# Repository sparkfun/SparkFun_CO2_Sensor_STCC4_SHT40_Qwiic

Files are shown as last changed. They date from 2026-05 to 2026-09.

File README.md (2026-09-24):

# SparkFun CO2 Sensor - STCC4/SHT41 (Qwiic)

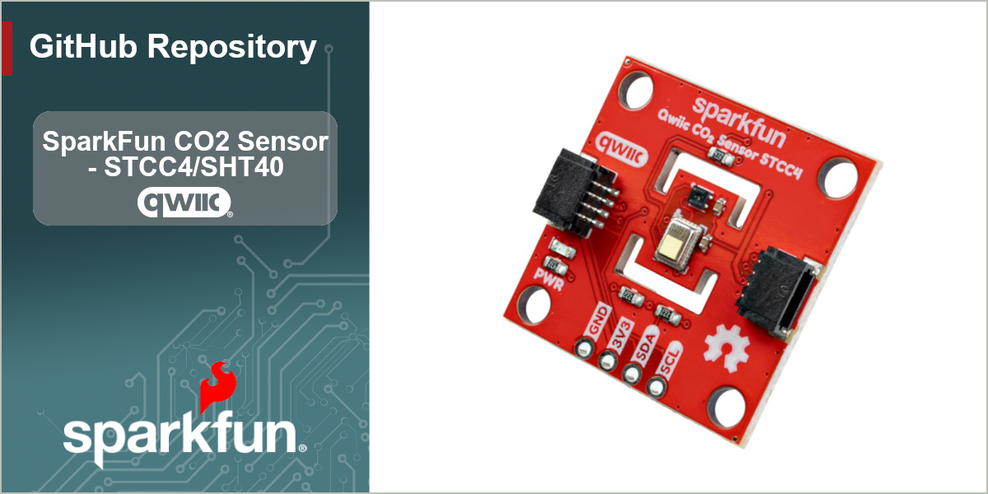
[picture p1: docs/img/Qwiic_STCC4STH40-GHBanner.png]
SparkFun CO2 Sensor - STCC4/SHT40 (Qwiic) (https://www.sparkfun.com/sparkfun-co2-sensor-stcc4-sht40-qwiic.html)


The SparkFun CO2 Sensor - STCC4/SHT40 (Qwiic) is a compact, plug-and-play air quality breakout built around the STCC4 CO₂ sensor paired with a Sensirion SHT41 temperature and humidity sensor for on-board environmental compensation. Connect via the Qwiic connector or the PTH header (GND, 3V3, SDA, SCL) and start reading calibrated CO₂ concentrations, temperature, and relative humidity over I2C in minutes — no external components required.

Designed for our [Qwiic ecosystem](https://www.sparkfun.com/qwiic), this 1" × 1" board plugs straight into any Qwiic-enabled microcontroller. A power LED confirms operation at a glance, and the four mounting holes make permanent installation straightforward. Whether you are monitoring indoor air quality, building a ventilation controller, or logging CO₂ trends in a greenhouse or classroom, the STCC4 delivers accurate, temperature- and humidity-compensated readings in a breadboard-friendly package.

## Repository Contents

* **/docs** - Documentation files for GitHub pages
* **/Documents** - Datasheets, additional product information
* **/Hardware** - KiCad design files (.kicad_sch, .kicad_pcb)
* **/Production** - Production panel files

## Documentation

* **[Library](https://github.com/sparkfun/SparkFun_STCC4_Arduino_Library)** - Arduino library for the SparkFun CO2 Sensor - STCC4/SHT40 (Qwiic).
* **[Hookup Guide](https://docs.sparkfun.com/SparkFun_CO2_Sensor_STCC4+SHT40/)** - Basic hookup guide for the SparkFun CO2 Sensor - STCC4/SHT40 (Qwiic).

## Product Versions

* **[SEN-31536](https://www.sparkfun.com/sparkfun-co2-sensor-stcc4-sht40-qwiic.htmlX)** - Initial release of the SparkFun CO2 Sensor - STCC4/SHT40 (Qwiic).

## License Information

This product is _**open source**_!

Please review the LICENSE.md file for license information.

If you have any questions or concerns about licensing, please contact technical support on our [SparkFun forums](https://forum.sparkfun.com/viewforum.php?f=152).

Distributed as-is; no warranty is given.

_- Your friends at SparkFun._

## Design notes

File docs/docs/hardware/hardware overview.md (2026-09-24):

# Hardware Overview

Let's take a closer look at this Qwiic breakout and the major components on it.

## STCC4 CO<sub>2</sub> Sensor

The STCC4 CO<sub>2</sub> sensor from Sensirion uses thermal conductivity (TC) to directly measure actual CO<sub>2</sub> concentrations from 400 to 5000 ppm (parts per million) with an accuracy of &plusmn;100ppm + 10% of the total readings. It outputs a calibrated digital signal that works with temperature and humidity data sent to it by the SHT40. It has a digital resolution of 1 ppm and a response time of ~20s. 

The STCC4 measures CO<sub>2</sub> with a digital resolution of 1ppm and a response time of 20s. It accepts a supply voltage between 2.7 to 5.5V (3.3V Typical) and consumes very little current. The STCC4 consumes an average of  Continuous Mode: 950&micro;A in continuous mode, 100&micro;A during single shot measurements, 55&micro;A during idle mode and 1&micro;A while in sleep mode (all values are with the internal heater OFF). The sensor communicates over I<sup>2</sup>C with two selectable addresses, **0x65** (Default) and **0x64**. The address can be adjusted using the ADDR jumper. Refer to the Solder Jumpers section below for more information. For a complete overview of the STCC4, refer to the [datasheet](/ref/STCC4.pdf)

### Calibration Algorithm

The STC44 features an automatic self-calibration (ASC) algorithm. This algorithm allows for stable readings over time with very little maintenance. The algorithm assumes the sensor is exposed to fresh air that contains a CO2 concentration of at least 400 ppm once a week. This algorithm requires an initial operation period of 12 hours for the sensor to achieve the sensor's measurement accuracy. Once this initial period completes, the sensor stores the first calibration state for subsequent power cycles. If the sensor is powered down for more than three hours, it's recommended to run the sensor for an hour to resume measurement accuracy.

## SHT40 Temperature and Humidity Sensor

The SHT40 is a highly accurate, low power temperature and humidity sensor that measures temperature with an accuracy of &plusmn;0.2&deg;C across a measurement range of -40 to +125&deg;C. It measures humidity with an accuracy of &plusmn;1.8% RH (relative humidity) from 0 to 100% RH. The sensor consumes very little power with a max current draw of 500&micro;A during measurements and a typical draw of 0.08&micro;A while the sensor's internal heater is off. Current draw with the heater on significantly raises the sensor's current draw to a max of 100mA.

## Connectors

### Qwiic Connectors

The board has a pair of Qwiic connectors to make it easy to integrate into a Qwiic circuit. These connect to the both the STCC4 and SHT40's I<sup>2</sup>C signals along with 3.3V and ground to power the board and communicate with the sensors.

### Plated Through-Hole (PTH) Header

The board also routes the same signals as the Qwiic connectors (SDA, SCL, 3.3V and Ground) to a 0.1"-spaced plated through-hole header for users who prefer a soldered connection.

## LED

The lone LED on this breakout is a red power status LED.

## Solder Jumpers

The board has three solder jumpers labeled <b>ADDR</b>, <b>I<sup>2</sup>C</b> and <b>LED</b>. The list below outlines their functionality, default states and any notes on their use:

* <b>ADDR</b> - The ADDR jumper sets the STCC4's I<sup>2</sup>C address to <b>0x64</b> by pulling the ADDR pin to GND. This jumper is CLOSED by default. Open the jumper to pull the ADDR pin to VDD and switch to the alternate address, <b>0x65</b>.
* <b>I<sup>2</sup>C</b> - The I<sup>2</sup>C jumper pulls the STCC4 and SHT40's SDA and SCL lines to 3.3V through a pair of <b>2.2k&ohm;</b> resistors. The jumper is CLOSED by default. Completely open this jumper to disable pullups if necessary.
* <b>LED</b> - The LED jumper completes the power LED circuit. It CLOSED by default. Open the jumper to disable the power LED.

## Board Dimensions

This breakout matches the Qwiic standard and measures 1" x 1" (22.5mm x 22.5mm) and has four mounting holes that fit a 4-40 screw.

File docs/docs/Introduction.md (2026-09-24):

---
slug: /
---

# Introduction

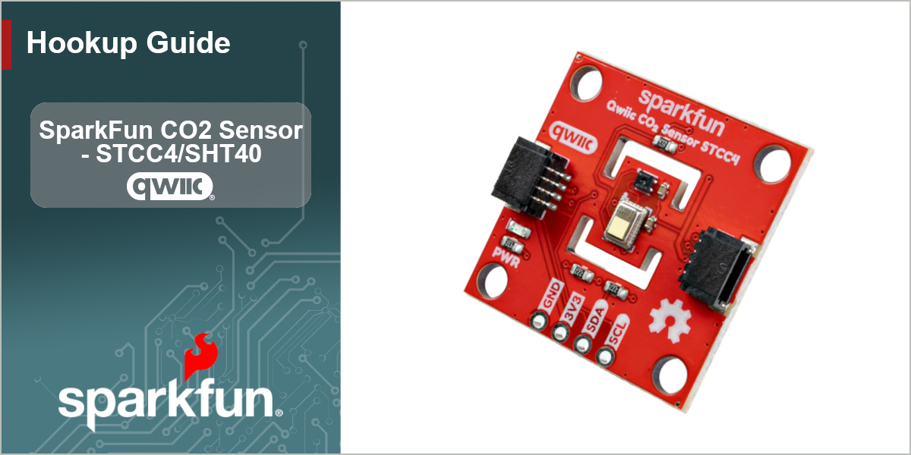
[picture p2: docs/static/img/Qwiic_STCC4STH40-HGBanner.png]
SparkFun CO2 Sensor - STCC4/SHT40 (Qwiic) Banner Image


The [SparkFun CO2 Sensor - STCC4/SHT40 (Qwiic)](https://www.sparkfun.com/sparkfun-co2-sensor-stcc4-sht40-qwiic.html) makes it easy to get highly-accurate, environmentally compensated indoor CO<sub>2</sub> data with no soldering required. This Qwiic breakout features a pair of isolated sensors from Sensirion, the STCC4 CO2 sensor and the SHT40 digital temperature and humidity sensor. These two sensors work together to output precise and environmentally compensated CO2 readings without any complicated wiring.

In order to follow along with this tutorial you'll need the SparkFun CO2 Sensor - STCC4/SHT40 (Qwiic) along with the following items:

* [SparkFun RedBoard IoT - RP2350](https://www.sparkfun.com/catalog/product/view/id/17811/s/sparkfun-iot-redboard-rp2350/) (or other Arduino development board)
* [Qwiic Cable](https://www.sparkfun.com/flexible-qwiic-cable-100mm.html)
* [USB-C Cable](https://www.sparkfun.com/usb-c-to-usb-c-cable-1-meter-flexible-silicone.html)

## Topics Covered

This document contains three main sections: **Quick Start Guide**, **Hardware** and **Software**.

The Quick Start Guide goes over assembling the CO2 Sensor in a Qwiic circuit with a compatible Arduino development board and jumps right into installing and uploading an example from the SparkFun STCC4 Arduino Library to get data from the sensor in just a few minutes.

The Hardware pages include a hardware overview that provides a detailed overview of the CO2 Sensor - STCC4/SHT40 (Qwiic) and all major components on the board. The Hardware Assembly page goes over the steps required to assemble and use the board to measure formaldehyde concentrations with a compatible Arduino development board.

The Software pages give instructions on how to install the SparkFun STCC4 Arduino Library and use some of the examples included in it.

## Resources and Documentation

The **Resources** page has the board design files (KiCad files & schematic), relevant documentation (datasheets, white papers, etc.) and other helpful links. The **Support** page has a troubleshooting section that includes any helpful tips specific to this board as well as information on how to receive technical support from SparkFun.

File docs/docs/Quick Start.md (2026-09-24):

# Quick Start Guide

In this Quick Start guide we'll connect the SparkFun CO<sub>2</sub> Sensor - STCC4/SHT40 (Qwiic) to a SparkFun RedBoard IoT - RP2350 and measure CO<sub>2</sub> concentrations along with temperature and humidity using the SparkFun STCC4 Arduino library. This guide assumes users have a working knowledge of the Qwiic ecosystem, Arduino IDE and using Arduino libraries. If you're not familiar with those topics or want to learn more about this Qwiic CO<sub>2</sub> breakout, we recommend reading through the other sections of the Hookup Guide.

## Qwiic Assembly

Since this is a Qwiic breakout, all we need to do is connect it to the RedBoard using a Qwiic cable and then plug the RedBoard into a computer over USB:

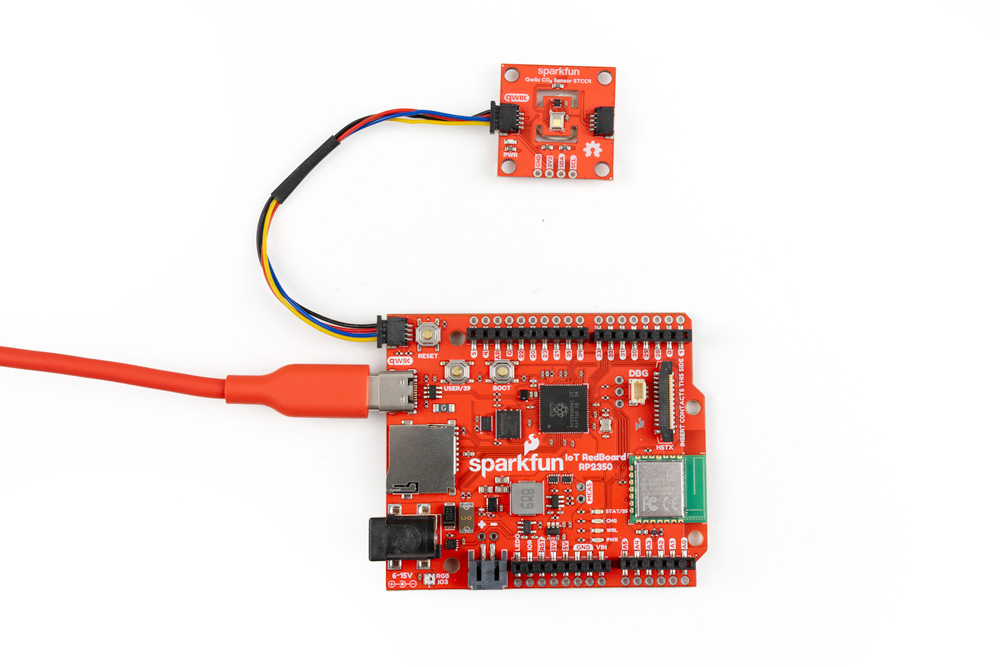
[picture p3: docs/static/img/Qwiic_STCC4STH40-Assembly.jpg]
Completed Qwiic assembly with the RedBoard IoT


## Arduino Example - Basic Readings

With everything wired up, let's use the first example in the STCC4 Arduino library to get CO<sub>2</sub>, temperature and humidity data. 

* Open the [Arduino IDE](https://www.arduino.cc/en/software/)
* Install the SparkFun STCC4 Arduino library by searching for "SparkFun STCC4" in the [Libraray Manager tool](https://docs.arduino.cc/software/ide-v2/tutorials/ide-v2-installing-a-library/). Note, this library requires the SparkFun Toolkit to be installed as well. Install that library by searching for "SparkFun Toolkit" in the Library Manager.
* Open "Example01-BasicReadings" from the STCC4 library. Select your Board and Port and click the "Upload" button.
* After the code finishes uploading, open the [serial monitor](https://docs.arduino.cc/software/ide-v2/tutorials/ide-v2-serial-monitor/) with the baud set to **15200**.

You should see readings for CO<sub>2</sub> in ppm along with temperature in &deg;C and humidity in %RH. On first-time power up of the STCC4, the manufacturer recommends an initial warm up period with the sensor operating in continuous measurement mode for 12 hours before CO<sub>2</sub> measurements achieve full accuracy. When powered down for more than three hours, the STCC4 can take up to an hour of operation to reach full accuracy. The sensor self-calibrates by assuming it sees fresh air (~400 ppm) at least once per week. The very first 20 seconds after the first ever power-up output a fixed bypass value of 390 ppm.

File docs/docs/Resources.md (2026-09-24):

For more information about the SparkFun CO2 Sensor - STCC4/SHT40 (Qwiic), take a look at the following resources:

* [Schematic](/ref/SparkFun_Qwiic_CO2_Sensor_STCC4.pdf)
* [KiCad Files](/ref/SparkFun_Qwiic_CO2_Sensor_STCC4.zip)
* [Board Dimensions](/ref/SparkFun_Qwiic_CO2_Sensor_STCC4.png)
* [Datasheet](/ref/STCC4.pdf) (STCC4)
* [Datasheet](/ref/SHT4X.pdf) (SHT4X)
* [SparkFun STCC4 Arduino Library](https://github.com/sparkfun/SparkFun_STCC4_Arduino_Library)

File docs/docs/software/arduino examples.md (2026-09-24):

# Arduino Examples

## Example 01 - Basic Readings

The first example demonstrates the simplest way to get data from the SparkFun CO<sub>2</sub> Sensor - STCC4/SHT40 (Qwiic). This example initializes the sensors and starts continuous measurement to read CO<sub>2</sub> concentration, temperature and relative humidity roughly once per second. Open the example by navigating to **File** > **Examples** > **SparkFun STCC4 Arduino Library** > **Example01_BasicReadings**. Select your Board and Port and click the "Upload" button. After the code finishes uploading, open the serial monitor with the baud set to **115200** and you should see readings for CO<sub>2</sub>C in ppm, temperature in &deg;C and relative humidity in %RH.

Note, for the first 20 seconds after first ever power up the STCC4 outputs a fixed bypass value for CO<sub>2</sub> of 390 ppm.

## Example 02 - Low Power Single Shot

Example 2 shows how to use the STCC4 in single shot mode to operate in a low power environment. This example sets up a 10 second sampling interval for the STCC4 to wake up, trigger a single shot measurement and then returns the sensor back to sleep mode:

``` c++
delay(kSamplingIntervalMs);

mySensor.exitSleepMode();
mySensor.measureSingleShot();
mySensor.readMeasurement();
```

You can adjust the sample interval to whatever you'd like by adjusting this line:

``` c++
const unsigned long kSamplingIntervalMs = 10000;
```

We recommend keeping it between 5 and 600 seconds to keep the STCC4's automatic self-calibration algorithm working correctly.

## Example 05 - Forced Recalibration

The fifth example shows how to force the STCC4 to perform a recalibration using a known reference concentration. This is helpful if you need to recalibrate the sensor immediately either during initial installation or if it cannot regularly see fresh air. 

Before running this example, make sure the board is in air with a known CO<sub>2</sub> concentration. Outdoor air works decently, it has an average concentration of 420 ppm. Then, set the `kReferenceCO2` value *below* your reference value. The example runs the STCC4 in continuous measurement mode for 60 seconds to stabilize the readings, then stops measurement. With the measurement stopped it performs the forced recalibration and prints out the correction the sensor applied. After the correction value is stored, the code resumes measurements in continuous mode.

## Example 06 - Pressure Compensation

The sixth example shows how to compensate for atmospheric pressure. The STCC4 assumes sea level air pressure (101,300 Pa) by default so if you're measuring at a different altitude or have a barometric pressure sensor handy to send true ambient air pressure this can improve the CO<sub>2</sub> measurement accuracy.

This example defaults to set the air pressure value for sea level, you can change that by adjusting this line:

``` c++
const uint32_t kAmbientPressurePa = 101325;
```

The code then uses that value to set the pressure compensation value here:

``` c++
mySensor.setPressureCompensation(kAmbientPressurePa);
```

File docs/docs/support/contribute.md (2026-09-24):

# Contribute

## Improve our Documentation

All of this documentation can be modified by you! Please help us make it better.

* These pages are contained in the [`docs` folder of the SparkFun CO2 Sensor STCC4/SHT40 (Qwiic) repository](https://github.com/sparkfun/SparkFun_CO2_Sensor_STCC4_SHT40_Qwiic/tree/main/docs).

### Submit a Correction

1. Fork this repo
2. Add your corrections or improvements to the markdown file
3. File a pull request with your changes, and enjoy making the ~~words~~ ~~worlds~~ world a better place.
    * Once received, the documentation specialist will automatically be notified.
    * We will review your suggested improvements to make sure they are correct and fit within our documentation standards.

## Improve our Hardware Design

This hardware design is open-source! Please help us make it better.

* Our board design files are contained in the [`Hardware` folder of the SparkFun CO2 Sensor STCC4/SHT40 (Qwiic) repository](https://github.com/sparkfun/SparkFun_CO2_Sensor_STCC4_SHT40_Qwiic/tree/main/Hardware).

### Submit a Design Improvement

1. Fork this repo
2. Add your design improvements
3. File a pull request with your changes, and enjoy making the ~~words~~ ~~worlds~~ world a better place.
    * Once received, the engineer in charge of the original design will automatically be notified.
    * We will review your suggested improvements, if they are within our board design standards and meet our product design requirements, we will flag these changes for our next board revision. *(Please note, that even if your suggestion is accepted, these changes may not be immediate. We may have to cycle through our current product inventory first.)*

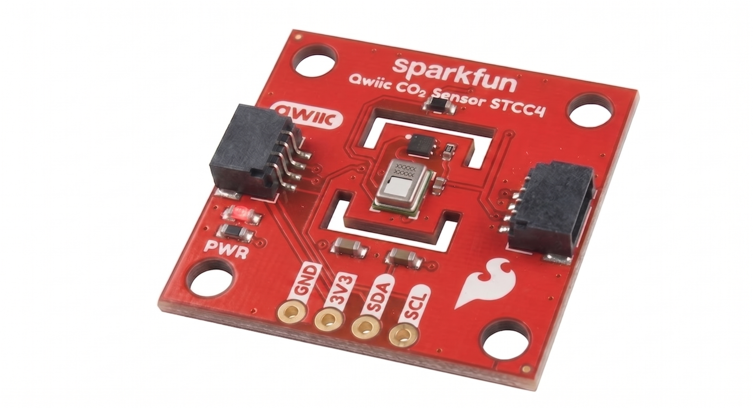
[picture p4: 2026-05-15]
Documents/images/STCC4.png

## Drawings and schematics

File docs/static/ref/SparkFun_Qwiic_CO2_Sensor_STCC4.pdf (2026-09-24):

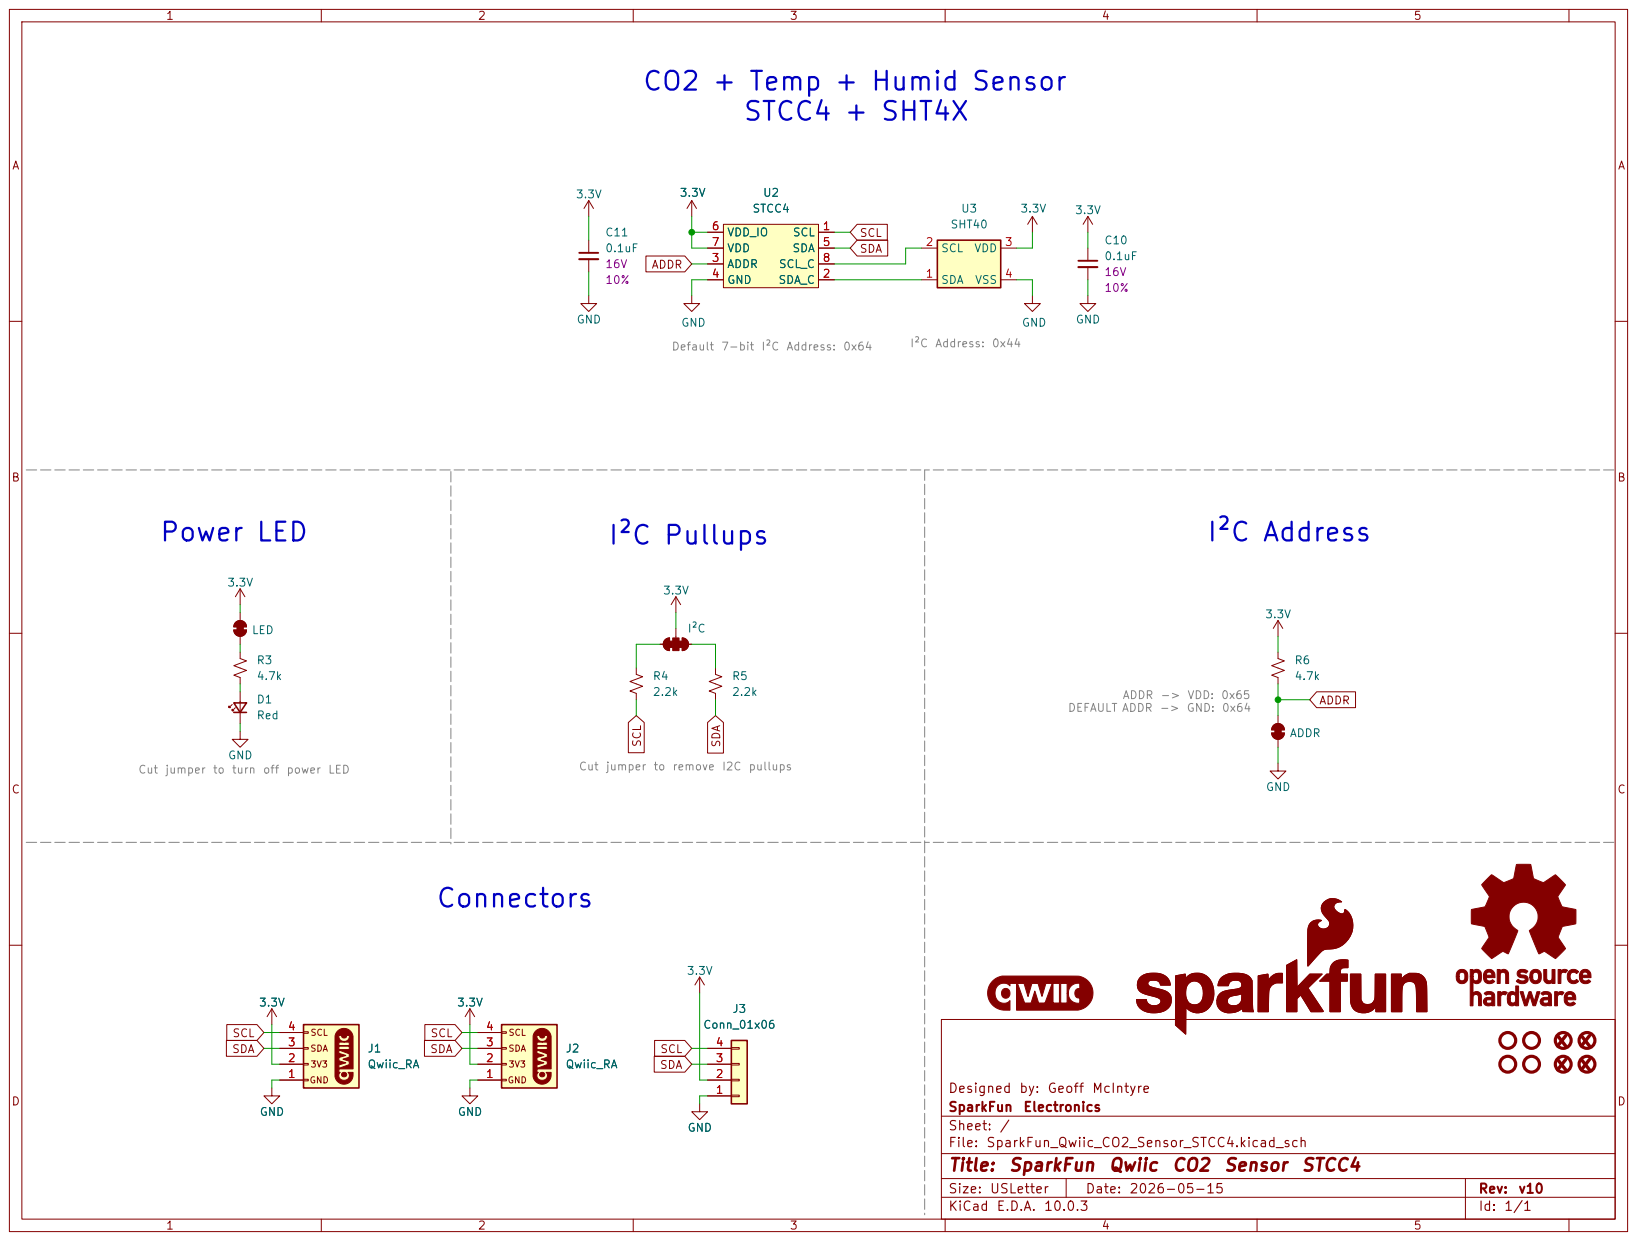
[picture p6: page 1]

Default 7-bit I²C Address: 0x64 Cut jumper to turn off power LED

ADDR -> GND: 0x64 I²C Pullups

Cut jumper to remove I2C pullups

Designed by: Geoff McIntyre
SparkFun Electronics
Sheet: /
File: SparkFun_Qwiic_CO2_Sensor_STCC4.kicad_sch
Title: SparkFun Qwiic CO2 Sensor STCC4

Size: USLetter | Rev: v10
KiCad E.D.A. 10.0.3 | Id: 1/1

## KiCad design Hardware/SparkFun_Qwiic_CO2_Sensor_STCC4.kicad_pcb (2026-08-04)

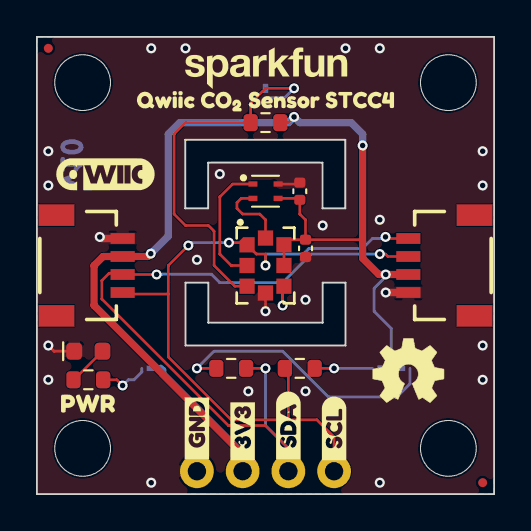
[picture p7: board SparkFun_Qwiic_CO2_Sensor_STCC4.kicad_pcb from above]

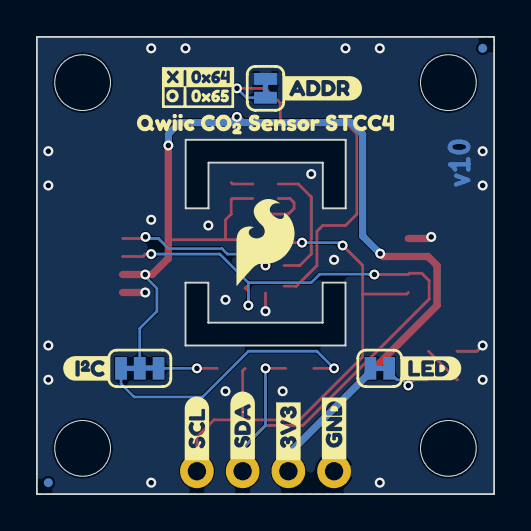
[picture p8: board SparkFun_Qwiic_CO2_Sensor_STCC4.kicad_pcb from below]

Board: 2 copper layers, 25.4 x 25.4 mm, 43 parts (16 on the bottom side), 11 nets.

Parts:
C10, C11: 0.1uF; C_0402_1005Metric
D1: Red; LED_0603_1608Metric_Red
FID1, FID2, FID3, FID4: Fiducial_0.5mm; Fiducial_0.5mm_Mask1mm
G4: OSHW_Logo; Creative_Commons_License
J1, J2: Qwiic_RA; JST_1x04_P1.0mm_Horizontal_SMD
J3: Conn_01x06; 1x04_P2.54mm
JP1: LED; Jumper_2_NC_Trace
JP2: I²C; Jumper_3_NC-2_Trace
JP3: ADDR; Jumper_2_NC_Trace
R3, R6: 4.7k; R_0603_1608Metric
R4, R5: 2.2k; R_0603_1608Metric
Ref**: Val**; OSHW_Logo_4mm
ST1, ST2, ST3, ST4: Standoff
U2: STCC4
U3: SHT40; Sensirion_DFN-4_1.5x1.5mm_P0.8mm_SHT4x_NoCentralPad
kibuzzard-6A0B3951: G***; kibuzzard-6A0B3951
kibuzzard-6A0B3970: G***; kibuzzard-6A0B3970
kibuzzard-6A063CE8: G***; kibuzzard-6A063CE8
kibuzzard-6A079B3E, kibuzzard-6A079B3E#2: G***; kibuzzard-6A079B3E
kibuzzard-6A079B36, kibuzzard-6A079B36#2: G***; kibuzzard-6A079B36
kibuzzard-6A07969C: G***; kibuzzard-6A07969C
kibuzzard-689A66E2: G***; kibuzzard-689A66E2
kibuzzard-689A66E9: G***; kibuzzard-689A66E9
kibuzzard-689A66EE: G***; kibuzzard-689A66EE
kibuzzard-689A66F4: G***; kibuzzard-689A66F4
kibuzzard-689A642E: G***; kibuzzard-689A642E
kibuzzard-689A6711: G***; kibuzzard-689A6711
kibuzzard-689A6718: G***; kibuzzard-689A6718
kibuzzard-689A6721: G***; kibuzzard-689A6721
kibuzzard-689A6728: G***; kibuzzard-689A6728
kibuzzard-689A6796: G***; kibuzzard-689A6796

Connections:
3.3V: C10.1, C11.1, J1.2, J2.2, J3.2, JP1.2 (B), JP2.2 (B), R6.2, U2.6 (VDD_IO), U2.7 (VDD), U3.3 (VDD)
ADDR: JP3.2 (B), R6.1, U2.3 (ADDR)
GND: C10.2, C11.2, D1.1 (K), J1.1, J2.1, J3.1, JP3.1 (A), U2.4 (GND), U3.4 (VSS)
unnamed: D1.2 (A), R3.1
unnamed: JP1.1 (A), R3.2
unnamed: JP2.1 (A), R5.1
unnamed: JP2.3 (C), R4.1
unnamed: U2.8 (SCL_C), U3.2 (SCL)
unnamed: U2.2 (SDA_C), U3.1 (SDA)
SCL: J1.4, J2.4, J3.4, R4.2, U2.1 (SCL)
SDA: J1.3, J2.3, J3.3, R5.2, U2.5 (SDA)

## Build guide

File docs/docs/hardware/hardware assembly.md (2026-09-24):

# Hardware Assembly

Let's go ahead and wire this up in a Qwiic circuit to start getting CO<sub>2</sub>, temperature and humidity data from this breakout.

## Qwiic Assembly

Since this is a Qwiic breakout, all we need to do is plug it into a Qwiic-comaptible development board, like the RedBoard IoT shown below, with a Qwiic cable. After that, plug the RedBoard into a computer over USB-C and we can move on to using the SparkFun STCC4 Arduino library to get data from the sensors:

Photo of completed circuit with the RedBoard IoT

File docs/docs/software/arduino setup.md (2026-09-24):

# Arduino Setup

This example assumes you are using the latest version of the Arduino IDE on your desktop. If this is your first time using Arduino IDE, library, or board add-on, please review the following tutorials.

- [Installing the Arduino IDE](https://learn.sparkfun.com/tutorials/installing-arduino-ide)
- [Installing an Arduino Library](https://learn.sparkfun.com/tutorials/installing-an-arduino-library)
- [Installing Board Definitions in the Arduino IDE](https://learn.sparkfun.com/tutorials/installing-board-definitions-in-the-arduino-ide)

## Installing the SparkFun STCC4 Arduino Library

This library is built using the [SparkFun Toolkit](https://github.com/sparkfun/SparkFun_Toolkit) so you'll need to make sure that is installed before using this library. Install the SparkFun Toolkit with the Arduino Library manager by searching "SparkFun Toolkit" and installing the latest version. Users who prefer manually installing Arduino Libraries can download it from the [GitHub Repository](https://github.com/sparkfun/SparkFun_Toolkit).

## Library Setup

The SparkFun STCC4 Arduino Library includes six examples that demonstrate how to use the STCC4 and SHT40 to get environmental data from the sensors. Install the library using the Arduino Library Manager tool by searching for "SparkFun STCC4" and install the latest version. If you'd prefer to manually install the library, you can download it from the [GitHub Repository](https://github.com/sparkfun/SparkFun_STCC4_Arduino_Library) or you can download a ZIP of the repository [here](https://github.com/sparkfun/SparkFun_STCC4_Arduino_Library/archive/refs/heads/main.zip).

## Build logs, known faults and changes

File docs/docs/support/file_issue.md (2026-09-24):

# Submit Issues

## Support

If you need technical assistance and more information on a product that is not working as you expected, visit the [SparkFun Community](https://community.sparkfun.com). The community forums are monitored by the SparkFun Technical Support Team and the SparkFun community as a whole.

## Existing Issue

Spot something wrong? Please check the list of reported and fixed issues  .  in this repository.

## Discrepancies in the Documentation

All of this documentation can be modified by you! Please help us make it better.

* The documentation files for these pages are contained in the [`docs` folder of the SparkFun CO2 Sensor STCC4/SHT40 (Qwiic) repository](https://github.com/sparkfun/SparkFun_CO2_Sensor_STCC4_SHT40_Qwiic/tree/main/docs).

### Spot something wrong?

If a section of the documentation is incorrect, please [open an issue](https://github.com/sparkfun/SparkFun_CO2_Sensor_STCC4_SHT40_Qwiic/issues) and let us know.

### Do you have a suggested correction?

1. With a GitHub account, fork this repo
2. Add your correction(s) or improvement(s) to the markdown file(s)
3. File a pull request with your changes, and enjoy making the ~~words~~ ~~worlds~~ world a better place.
    * Once received, the documentation specialist will automatically be notified.
    * We will review your suggested improvement(s) to make sure they are correct and fit within our documentation standards.

## Problems in the Hardware Design

All of our designs are open-source! Please help us make it better.

* Our board design files are contained in the [`Hardware` folder of the SparkFun CO2 Sensor STCC4/SHT40 (Qwiic) repository](https://github.com/sparkfun/SparkFun_CO2_Sensor_STCC4_SHT40_Qwiic/tree/main/Hardware).

### Does something not make sense?

If part of the design is confusing, please [open an issue](https://github.com/sparkfun/SparkFun_CO2_Sensor_STCC4_SHT40_Qwiic/issues) and let us know.

### Did we forget to include an important function of the board?

Please keep in mind that we may intentionally exclude certain functions of the board to meet our product design requirements.

If part of the board's functionality is missing, please [open an issue](https://github.com/sparkfun/SparkFun_CO2_Sensor_STCC4_SHT40_Qwiic/issues) and file a feature request.

### Do you wish to contribute directly to improving the board design?

1. With a GitHub account, Fork this repo
2. Add your design improvement(s)
3. File a pull request with your changes, and enjoy making the ~~words~~ ~~worlds~~ world a better place.
    * Once received, the engineer in charge of the original design will automatically be notified.
    * We will review your suggested improvement(s), if they are within our board design standards and meet our product design requirements, we will flag these changes for our next board revision. *(Please note, that even if your suggestion is accepted, these changes may not be immediate. We may have to cycle through our current product inventory first.)*

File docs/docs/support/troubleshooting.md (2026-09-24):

# Troubleshooting

## Compensation Algorithm Warm Up Period

On first-time power up of the STCC4, the manufacturer recommends an initial warm up period with the sensor operating in continuous measurement mode for 12 hours before CO<sub>2</sub> measurements achieve full accuracy. When powered down for more than three hours, the STCC4 can take up to an hour of operation to reach full accuracy. The sensor self-calibrates by assuming it sees fresh air (~400 ppm) at least once per week. The very first 20 seconds after the first ever power-up output a fixed bypass value of 390 ppm.

## Support

If you need technical assistance or more information on a product that is not working as you expected, we recommend heading on over to the [SparkFun Technical Assistance](https://www.sparkfun.com/technical_assistance) page for some initial troubleshooting.

If you need technical assistance and more information on a product that is not working as you expected, visit the [SparkFun Community](https://community.sparkfun.com). The community forums are monitored by the SparkFun Technical Support Team and the SparkFun community as a whole. If this is your first visit to our forum, you'll need to create a [Forum Account](https://forum.sparkfun.com/ucp.php?mode=register) to post questions.

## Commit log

2026-05-18 Finalized the Silkscreen
    [SparkFun_Qwiic_CO2_Sensor_STCC4.kicad_pcb]
2026-05-19 Added changes from Design Review
    - Nudged vias
    - Replaced "pullup" capacitors
    - Adjusted measures alignment
    - Adjusted solder paste expansion
    - Swapped Flame and OSHW Logos
    [SparkFun_Qwiic_CO2_Sensor_STCC4.kicad_pcb, SparkFun_Qwiic_CO2_Sensor_STCC4.kicad_sch]
2026-05-19 Moved I2C Address Table
    [SparkFun_Qwiic_CO2_Sensor_STCC4.kicad_sch]
2026-05-22 Updates Edge Cut polygon to an outline and adds "Route Out" to ensure proper manufacturing
    [SparkFun_Qwiic_CO2_Sensor_STCC4.kicad_pcb]
2026-07-07 Updated to v10 for REDs
    [SparkFun_Qwiic_CO2_Sensor_STCC4.kicad_pcb, SparkFun_Qwiic_CO2_Sensor_STCC4.kicad_sch]
2026-08-04 Updated I2C Address
    [SparkFun_Qwiic_CO2_Sensor_STCC4.kicad_pcb, SparkFun_Qwiic_CO2_Sensor_STCC4.kicad_sch]

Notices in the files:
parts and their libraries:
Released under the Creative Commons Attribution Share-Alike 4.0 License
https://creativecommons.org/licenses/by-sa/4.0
